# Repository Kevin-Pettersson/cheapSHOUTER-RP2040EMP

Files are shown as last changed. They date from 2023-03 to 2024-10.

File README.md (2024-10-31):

# cheapSHOUTER-RP2040EMP
Improved version of the great ChipSHOUTER-PicoEMP, this version has made cuts to the BOM and has added functionality inclduing: built in RP2040 instead of using a PICO, USB-C, LIPO charger + protection, USB isolation (not true isolation, allows to disconnect VBUS) + TVS diodes, buzzer, cleaner layout, and more.

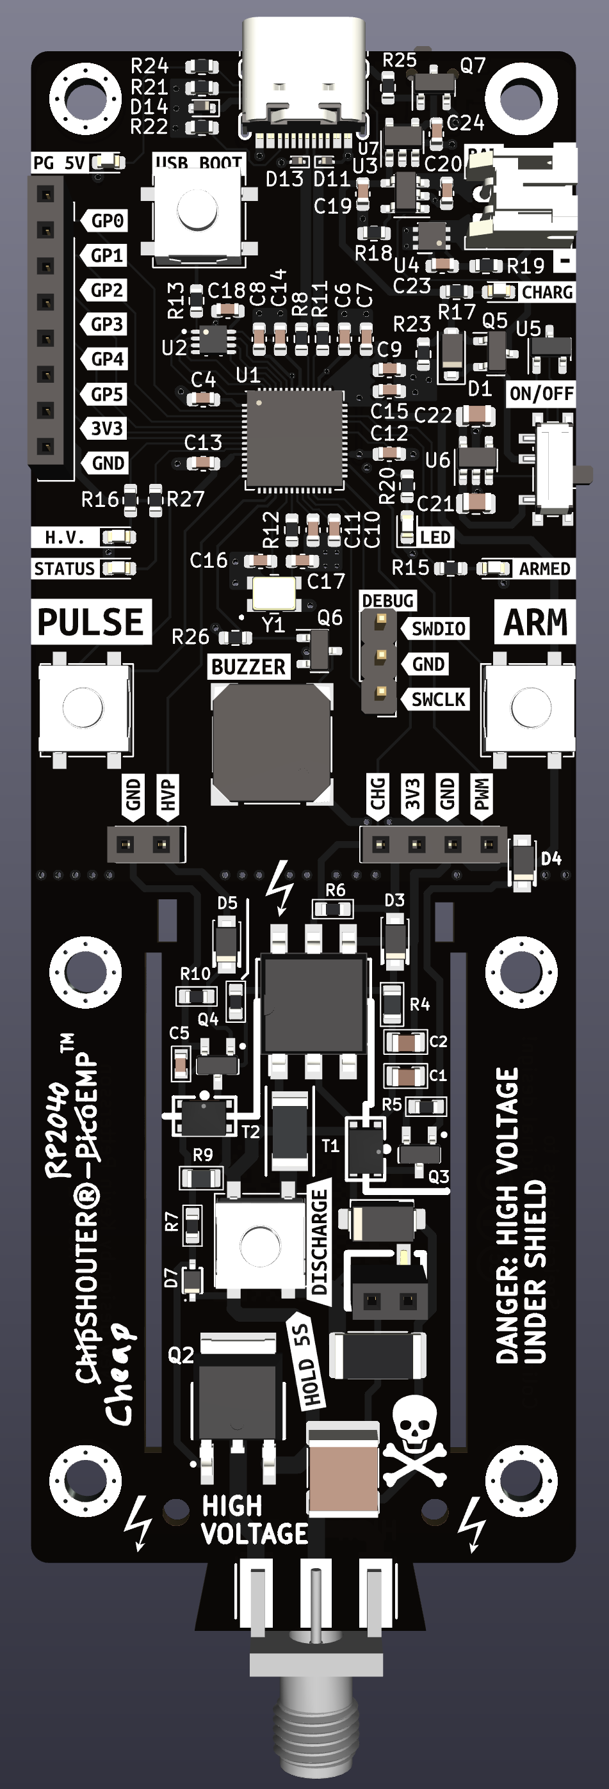
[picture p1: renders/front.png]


## Contributors
- Colin O'Flynn (original HW design)
- Nezza (original FW)
- Kevin Pettersson 
- Linus Backlund
- Wilhelm Westermark

## Firmware
The firmware is a slightly tweaked version of the c-firmware from the original repo. The changes adapts the button logic to the active-high board design and activates the buzzer for a short period upon manual pulses.

## License

This work is licensed under a [Creative Commons Attribution-ShareAlike 3.0 International License][cc-by-sa].

[cc-by-sa]: http://creativecommons.org/licenses/by-sa/3.0/
[cc-by-sa-image]: https://licensebuttons.net/l/by-sa/3.0/88x31.png
[cc-by-sa-shield]: https://img.shields.io/badge/License-CC%20BY--SA%203.0-lightgrey.svg

ChipSHOUTER is a trademark of NewAE Technology Inc., registered in the US, European Union, and other jurisdictions.
PicoEMP is a trademark of NewAE Technology Inc.

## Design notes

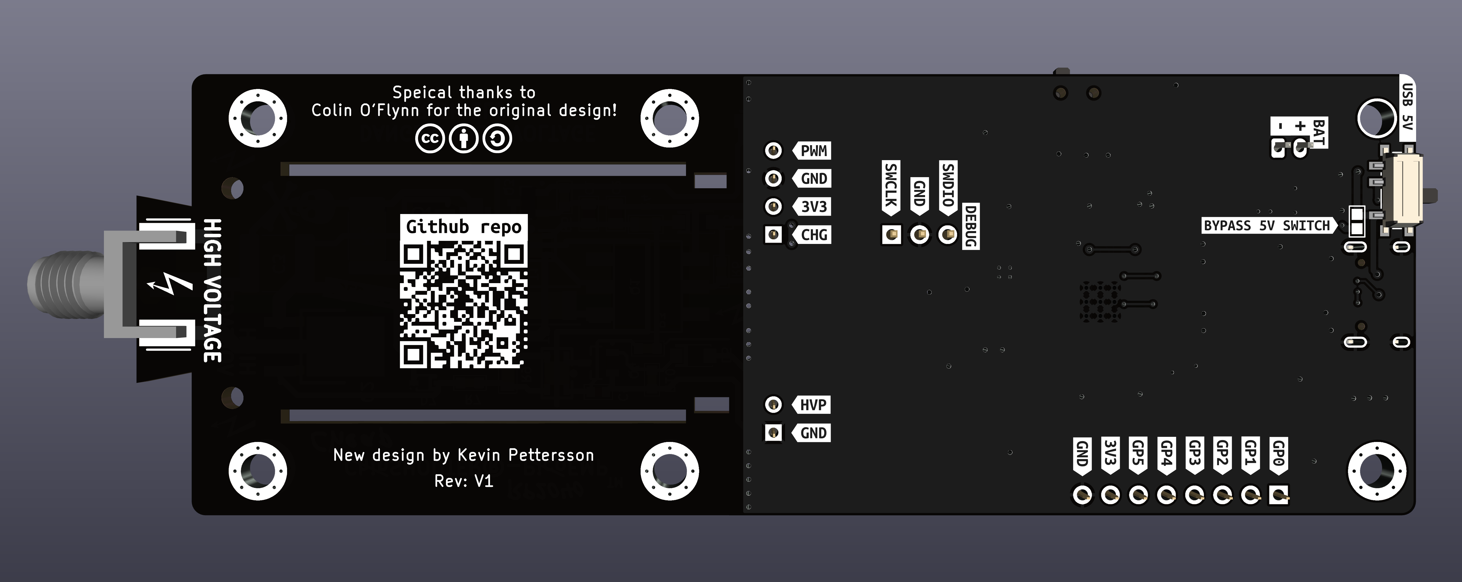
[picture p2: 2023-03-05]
renders/back_rotated.png

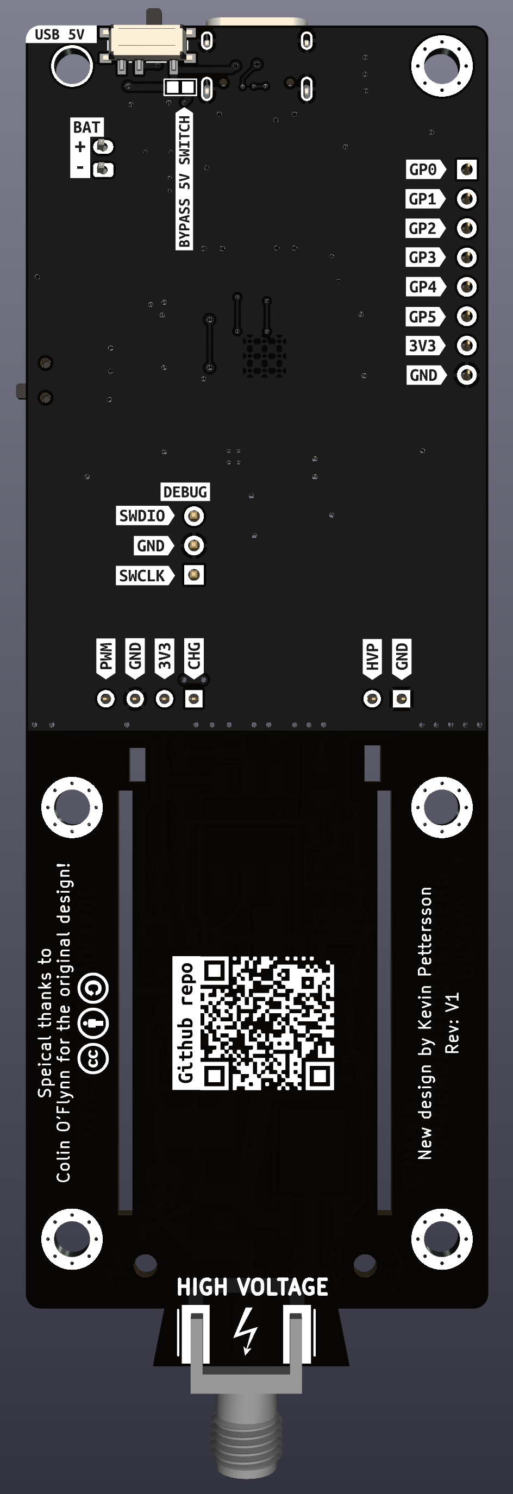
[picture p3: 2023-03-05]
renders/back.png

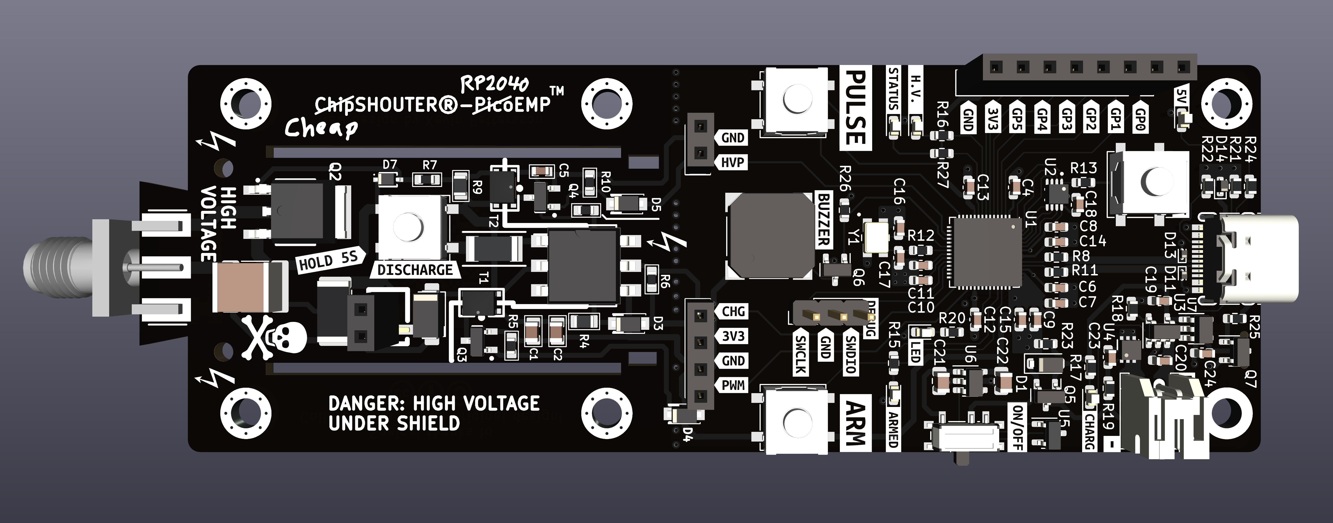
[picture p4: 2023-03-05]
renders/front_rotated.png

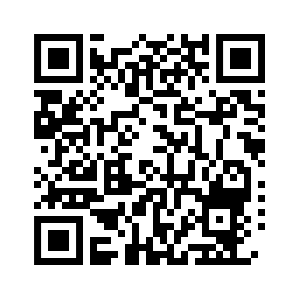
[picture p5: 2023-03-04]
qr_repo.png

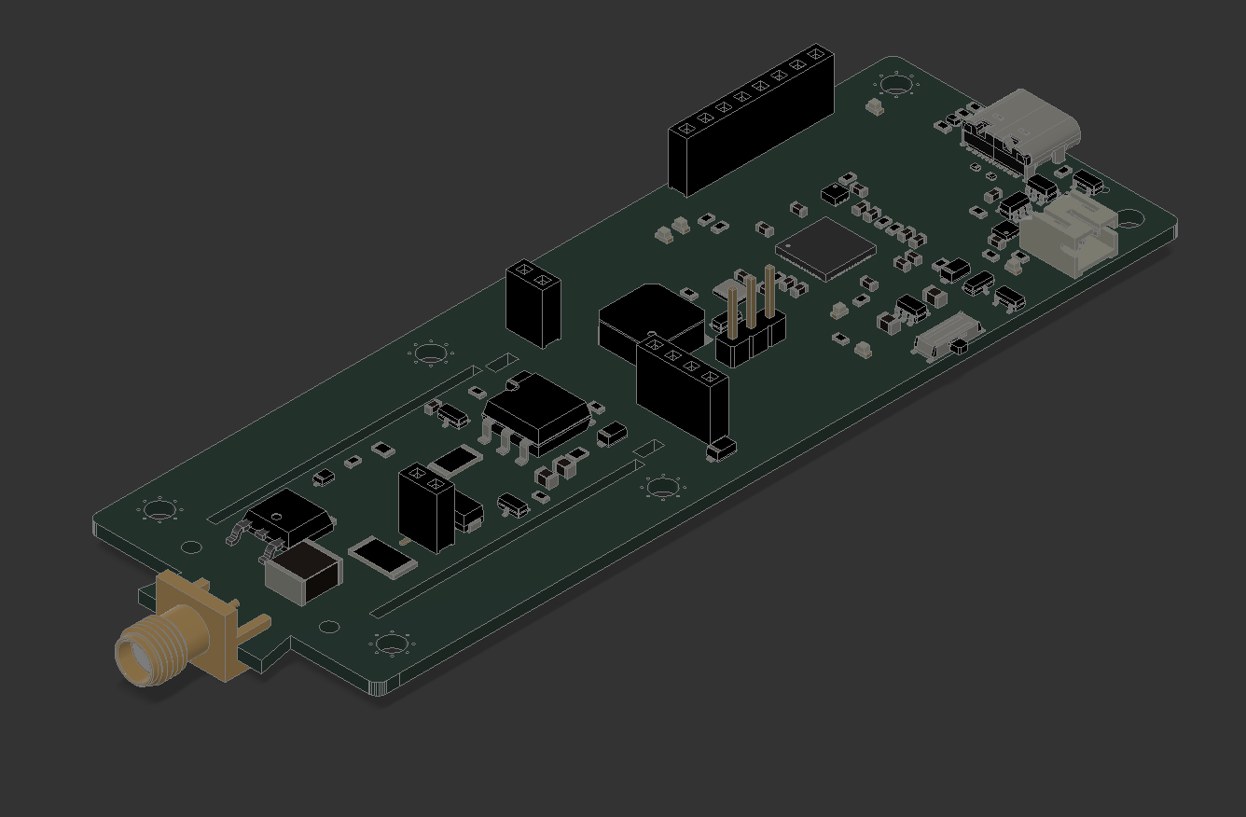
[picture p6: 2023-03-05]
renders/3d_model.png

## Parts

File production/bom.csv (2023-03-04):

Designator | Footprint | Quantity | Value | LCSC Part #
_2, |  | 2
BATTERY1 | JST_PH_S2B-PH-K_1x02_P2.00mm_Horizontal | 1 | Conn_01x02_Female
BZ1 | PUIAudio_SMT_0825_S_4_R | 1 | MLT-7525
C1, C2 | _Users_cofly_Dropbox (NewAE Technology Inc)_engineering_altium_Libraries_footprints_CAPC0805_M.PcbLib_CAPC0805_M | 2 | 4.7uF/50V
C10 | 0603 | 1 | 1u
C11 | 0603 | 1 | 100n
C12 | 0603 | 1 | 100n
C13 | 0603 | 1 | 100n
C14 | 0603 | 1 | 100n
C15 | 0603 | 1 | 1u
C16 | 0603 | 1 | 39p
C17 | 0603 | 1 | 39p
C18 | 0603 | 1 | 1u
C19 | 0603 | 1 | 10u
C20 | 0603 | 1 | 10u
C21 | 0805 | 1 | 47u
C22 | 0805 | 1 | 47u
C23 | 0603 | 1 | 100n
C24 | 0603 | 1 | 10u
C3 | 2220 | 1 | 0.47uF,630V,X7T
C4 | 0603 | 1 | 100n
C5 | _Users_cofly_Dropbox (NewAE Technology Inc)_engineering_altium_Libraries_footprints_CAPC0603_M.PcbLib_CAPC0603_M | 1 | 100n
C6 | 0603 | 1 | 100n
C7 | 0603 | 1 | 100n
C8 | 0603 | 1 | 100n
C9 | 0603 | 1 | 100n
D1 | D_SOD-123F | 1 | DS14W
D10 | 0603 | 1 | PICO_LED1
D11, D13 | D_SOD-923 | 2 | LESD9L5.0T5G
D12 | 0603 | 1 | STATUS1
D14 | D_SOD-523 | 1 | PESDNC5D7VU
D15 | 0603 | 1 | 5V_PWR
D2 | _Users_cofly_Dropbox (NewAE Technology Inc)_engineering_altium_Libraries_footprints_DO-214AC.PcbLib_DO-214AC | 1 | MURA160T3G
D3, D4, D5 | _Users_cofly_Dropbox (NewAE Technology Inc)_engineering_altium_NewAE_AltiumLib.DBLib/main_DSS13UTR | 3 | GOODWORK A7
D6 | 0603 | 1 | CHARGING
D7 | _Users_colin_Dropbox (NewAE Technology Inc)_engineering_altium_Libraries_footprints_SOD323.PcbLib_SOD323 | 1 | MM3Z18VB
D8 | 0603 | 1 | CHARGE_ON1
D9 | 0603 | 1 | H.V_DETECTED1
J1 | _Users_cofly_Dropbox (NewAE Technology Inc)_engineering_altium_Libraries_footprints_CON-SMA-MALE-PCB-EDGE062.PcbLib_CON-SMA-MALE-PCB-EDGE062 | 1 | EDGE-SMA
J2 | USB_C_Receptacle_HRO_TYPE-C-31-M-12 | 1 | USB_C_Receptacle_USB2.0 | C709357
J3 | _Users_cofly_Dropbox (NewAE Technology Inc)_engineering_altium_Libraries_footprints_GCT_BG306.PcbLib_BG306-R2-2PIN | 1 | BG306-02-A-2-0400-L-G
J5 | PinHeader_1x03_P2.54mm_Vertical | 1 | Conn_01x03_Socket
J6 | PinSocket_1x08_P2.54mm_Vertical | 1 | Conn_01x08_Socket
JP1 | SolderJumper-2_P1.3mm_Open_Pad1.0x1.5mm | 1 | ~
MH1_5, MH1_4, MH1_3, MH1_2, MH1 | _Users_colin_Dropbox (NewAE Technology Inc)_engineering_altium_Libraries_footprints_MOUNT_M3_TIGHT.PcbLib_MOUNT_M3_TIGHT | 5 | M3, Tight Fit
P2 | HDR1X2 | 1 | Header 2
P3 | HDR1X4 | 1 | Header 4
Q1 | SOP254P952X470-6N | 1 | LDA111STR
Q2 | _Users_cofly_Dropbox (NewAE Technology Inc)_engineering_altium_Libraries_footprints_DPAK_TO-252AA_M.PcbLib_DPAK_TO-252AA_M | 1 | RGT16BM65DTL
Q3, Q4 | _Users_cofly_Dropbox (NewAE Technology Inc)_engineering_altium_Libraries_footprints_SOT95P245X110-3M.PcbLib_SOT95P245X110-3M | 2 | AO3422
Q5 | SOT-23 | 1 | FSS2301S
Q6 | SOT-23 | 1 | FSS2302S
Q7 | SOT-23 | 1 | FSS2302S
R1 | _Users_cofly_Dropbox (NewAE Technology Inc)_engineering_altium_NewAE_AltiumLib.DBLib/main_RESC5025X06N | 1 | 20M
R10, R5 | _Users_cofly_Dropbox (NewAE Technology Inc)_engineering_altium_Libraries_footprints_RESC1608X55N.PcbLib_RESC1608X55N | 2 | 1k
R11 | 0603 | 1 | 27
R12 | 0603 | 1 | 200
R13 | 0603 | 1 | 1K
R15 | 0603 | 1 | 1k
R16 | 0603 | 1 | 1k
R17 | 0603 | 1 | 2k
R18 | 0603 | 1 | 2k
R19 | 0603 | 1 | 100
R2 | 2512 | 1 | 360k
R20 | 0603 | 1 | 1k
R21 | 0603 | 1 | 5.1K | C23186
R22 | 0603 | 1 | 5.1K
R23 | 0603 | 1 | 10k
R24 | 0603 | 1 | 1k
R25 | 0603 | 1 | 100k
R26 | 0603 | 1 | 100k
R27 | 0603 | 1 | 1k
R3 | _Users_cofly_Dropbox (NewAE Technology Inc)_engineering_altium_NewAE_AltiumLib.DBLib/main_RESC1608X55N | 1 | 10R
R4 | _Users_cofly_Dropbox (NewAE Technology Inc)_engineering_altium_Libraries_footprints_RESC2012X70N.PcbLib_RESC2012X70N | 1 | 75R
R6 | _Users_colin_Dropbox (NewAE Technology Inc)_engineering_altium_Libraries_footprints_RESC1608X55N.PcbLib_RESC1608X55N | 1 | 22k
R7 | _Users_cofly_Dropbox (NewAE Technology Inc)_engineering_altium_Libraries_footprints_RESC1608X55N.PcbLib_RESC1608X55N | 1 | 10R
R8 | 0603 | 1 | 27
R9 | _Users_cofly_Dropbox (NewAE Technology Inc)_engineering_altium_Libraries_footprints_RESC2012X70N.PcbLib_RESC2012X70N | 1 | 2k
SW1 | _Users_cofly_Dropbox (NewAE Technology Inc)_engineering_altium_Libraries_footprints_CK_KSC7J.PcbLib_CK_KSC7J | 1 | ARM
SW2 | _Users_cofly_Dropbox (NewAE Technology Inc)_engineering_altium_Libraries_footprints_CK_KSC7J.PcbLib_CK_KSC7J | 1 | PULSE
SW3 | _Users_colin_Dropbox (NewAE Technology Inc)_engineering_altium_Libraries_footprints_CK_KSC7J.PcbLib_CK_KSC7J | 1 | TL3301AF160QJ
SW4 | _Users_cofly_Dropbox (NewAE Technology Inc)_engineering_altium_Libraries_footprints_CK_KSC7J.PcbLib_CK_KSC7J | 1 | SW_SPST
SW5, SW6 | SW_SPDT_PCM12 | 2 | SSSS811101
T1, T2 | _Users_cofly_Dropbox (NewAE Technology Inc)_engineering_altium_Libraries_footprints_ATB322524.PcbLib_ATB322524 | 2 | ATB322524
U1 | QFN-56-1EP_7x7mm_P0.4mm_EP3.2x3.2mm | 1 | RP2040 | C2040
U2 | IC_W25Q16JVUXIQ_TR | 1 | W25Q128JVSIQ
U3 | SOT-23-5 | 1 | LP4054H
U4 | DFN-6-1EP_2x2mm_P0.65mm_EP1x1.6mm | 1 | XB6536A
U5 | SOT-23-3 | 1 | ME2807
U6 | SOT-23-5 | 1 | LP3992-3.3
U7 | SOT-23-5 | 1 | LPW5206
Y1 | X322512MSB4SI | 1 | X322512MSB4SI

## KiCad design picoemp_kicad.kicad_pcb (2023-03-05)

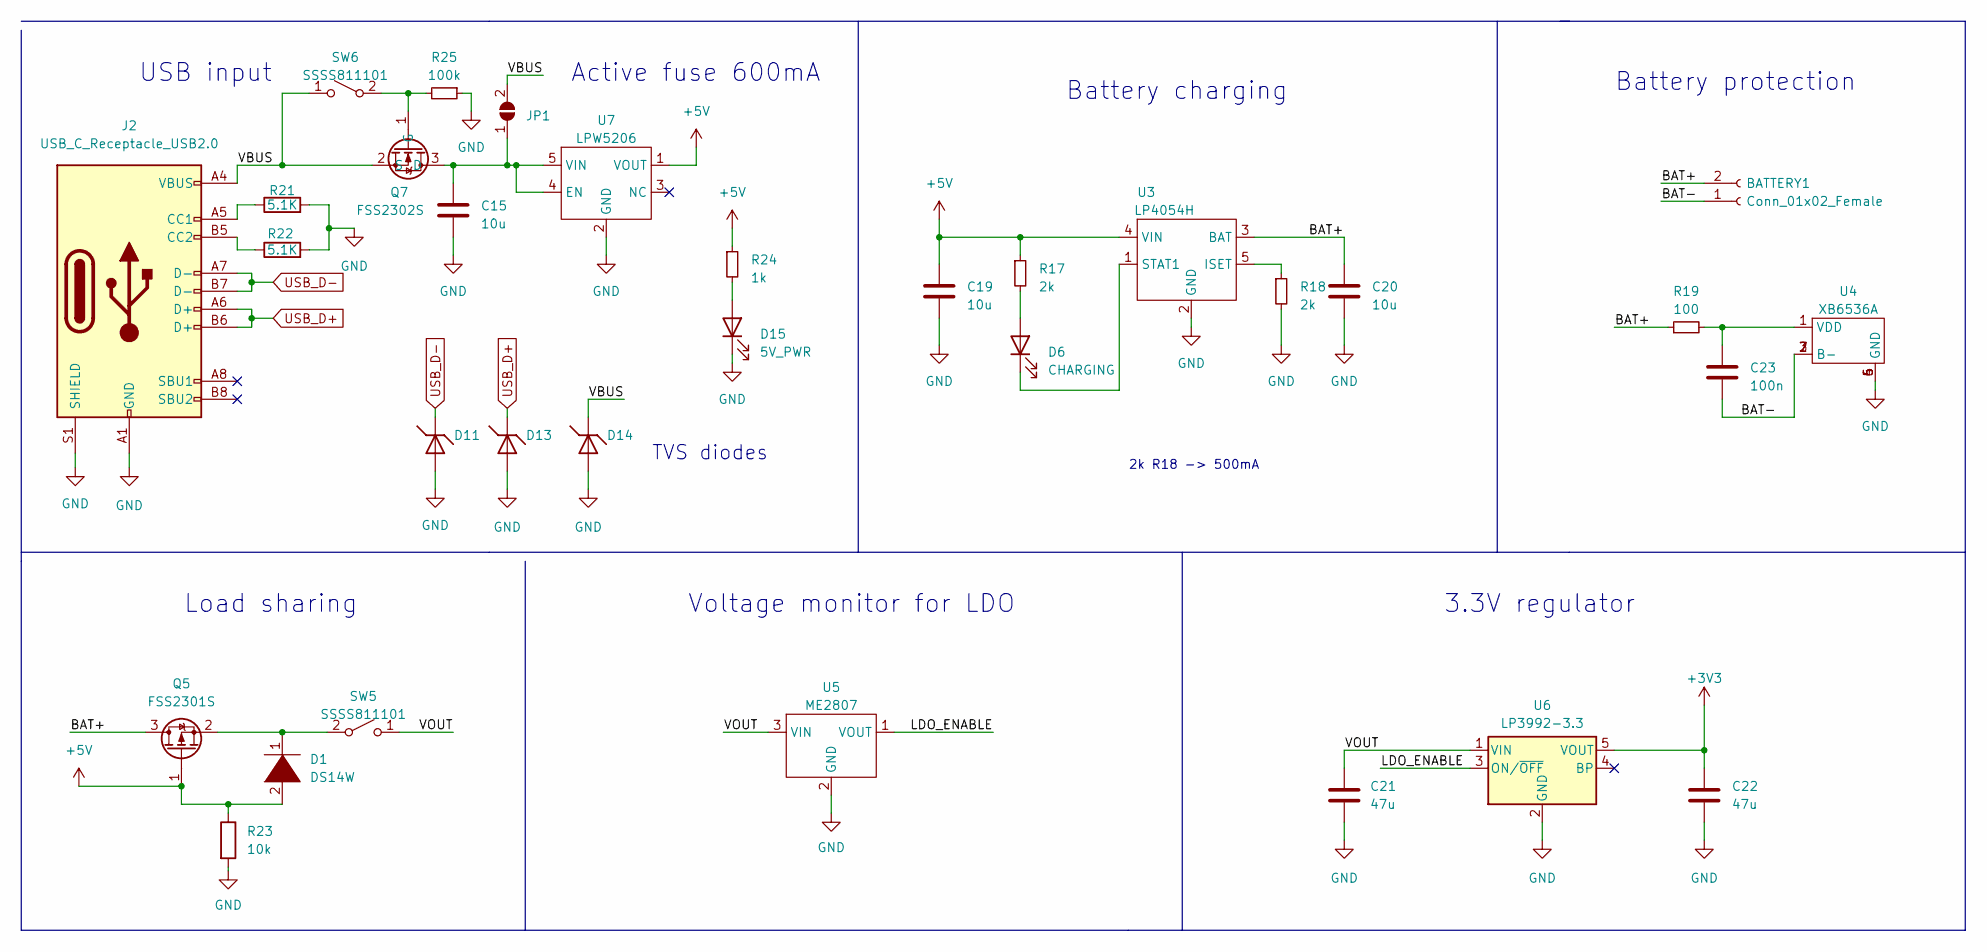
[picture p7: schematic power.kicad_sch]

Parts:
BATTERY1: Conn_01x02_Female; JST_PH_S2B-PH-K_1x02_P2.00mm_Horizontal
C15, C19, C20: 10u; C_0603_1608Metric
C21, C22: 47u; C_0805_2012Metric
C23: 100n; C_0603_1608Metric
D1: DS14W; D_SOD-123F
D6: CHARGING; LED_0603_1608Metric
D11, D13: LESD9L5.0T5G; D_SOD-923
D14: PESDNC5D7VU; D_SOD-523
D15: 5V_PWR; LED_0603_1608Metric
J2: USB_C_Receptacle_USB2.0; USB_C_Receptacle_HRO_TYPE-C-31-M-12; JLCPCB Part # C709357
JP1: SolderJumper-2_P1.3mm_Open_Pad1.0x1.5mm
Q5: FSS2301S; SOT-23
Q7: FSS2302S; SOT-23
R17, R18: 2k; R_0603_1608Metric
R19: 100; R_0603_1608Metric
R21: 5.1K; R_0603_1608Metric; JLCPCB Part # C23186
R22: 5.1K; R_0603_1608Metric
R23: 10k; R_0603_1608Metric
R24: 1k; R_0603_1608Metric
R25: 100k; R_0603_1608Metric
SW5, SW6: SSSS811101; SW_SPDT_PCM12
U3: LP4054H; SOT-23-5
U4: XB6536A; DFN-6-1EP_2x2mm_P0.65mm_EP1x1.6mm
U5: ME2807; SOT-23-3
U6: LP3992-3.3; SOT-23-5
U7: LPW5206; SOT-23-5

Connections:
+5V: C19.1, D1.2 (K), Q5.1 (G), R17.1, R23.1, R24.1, U3.4 (VIN), U7.1 (VOUT)
/Power/BAT+: BATTERY1.2 (Pin_1), C20.1, Q5.3 (D), R19.1, U3.3 (BAT)
/Power/BAT-: BATTERY1.1 (Pin_2), C23.2, U4.2 (B-), U4.3 (B-), U4.7 (B-)
/Power/LDO_ENABLE: U5.1 (VOUT), U6.3 (ON/~OFF)
/Power/VBUS: D14.1 (K), J2.A4 (VBUS), J2.A9 (VBUS), J2.B4 (VBUS), J2.B9 (VBUS), JP1.2 (B), Q7.2 (S), SW6.1 (B)
/Power/VOUT: C21.1, SW5.1 (B), U5.3 (VIN), U6.1 (VIN)
GND: C15.2, C19.2, C20.2, C21.2, C22.2, D11.2 (A), D13.2 (A), D14.2 (A), D15.1 (K), J2.A1 (GND), J2.A12 (GND), J2.B1 (GND), J2.B12 (GND), J2.S1 (SHIELD), R18.2, R21.2, R22.2, R23.2, R25.1, U3.2 (GND), U4.4 (GND), U4.5 (GND), U4.6 (GND), U5.2 (GND), U6.2 (GND), U7.2 (GND); also elsewhere on the board
unnamed: D1.1 (A), Q5.2 (S), SW5.2 (A)
unnamed: D6.2 (A), R17.2
unnamed: D6.1 (K), U3.1 (STAT1)
unnamed: D15.2 (A), R24.2
unnamed: J2.A5 (CC1), R21.1
unnamed: J2.B5 (CC2), R22.1
unnamed: Q7.1 (G), R25.2, SW6.2 (A)
unnamed: R18.1, U3.5 (ISET)
unnamed: C23.1, R19.2, U4.1 (VDD)
USB_D+: D13.1 (K), J2.A6 (D+), J2.B6 (D+); also elsewhere on the board
USB_D-: D11.1 (K), J2.A7 (D-), J2.B7 (D-); also elsewhere on the board

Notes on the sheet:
2k R18 -> 500mA
Battery protection
USB input
Battery charging
Voltage monitor for LDO
Active fuse 600mA
TVS diodes
3.3V regulator
Load sharing

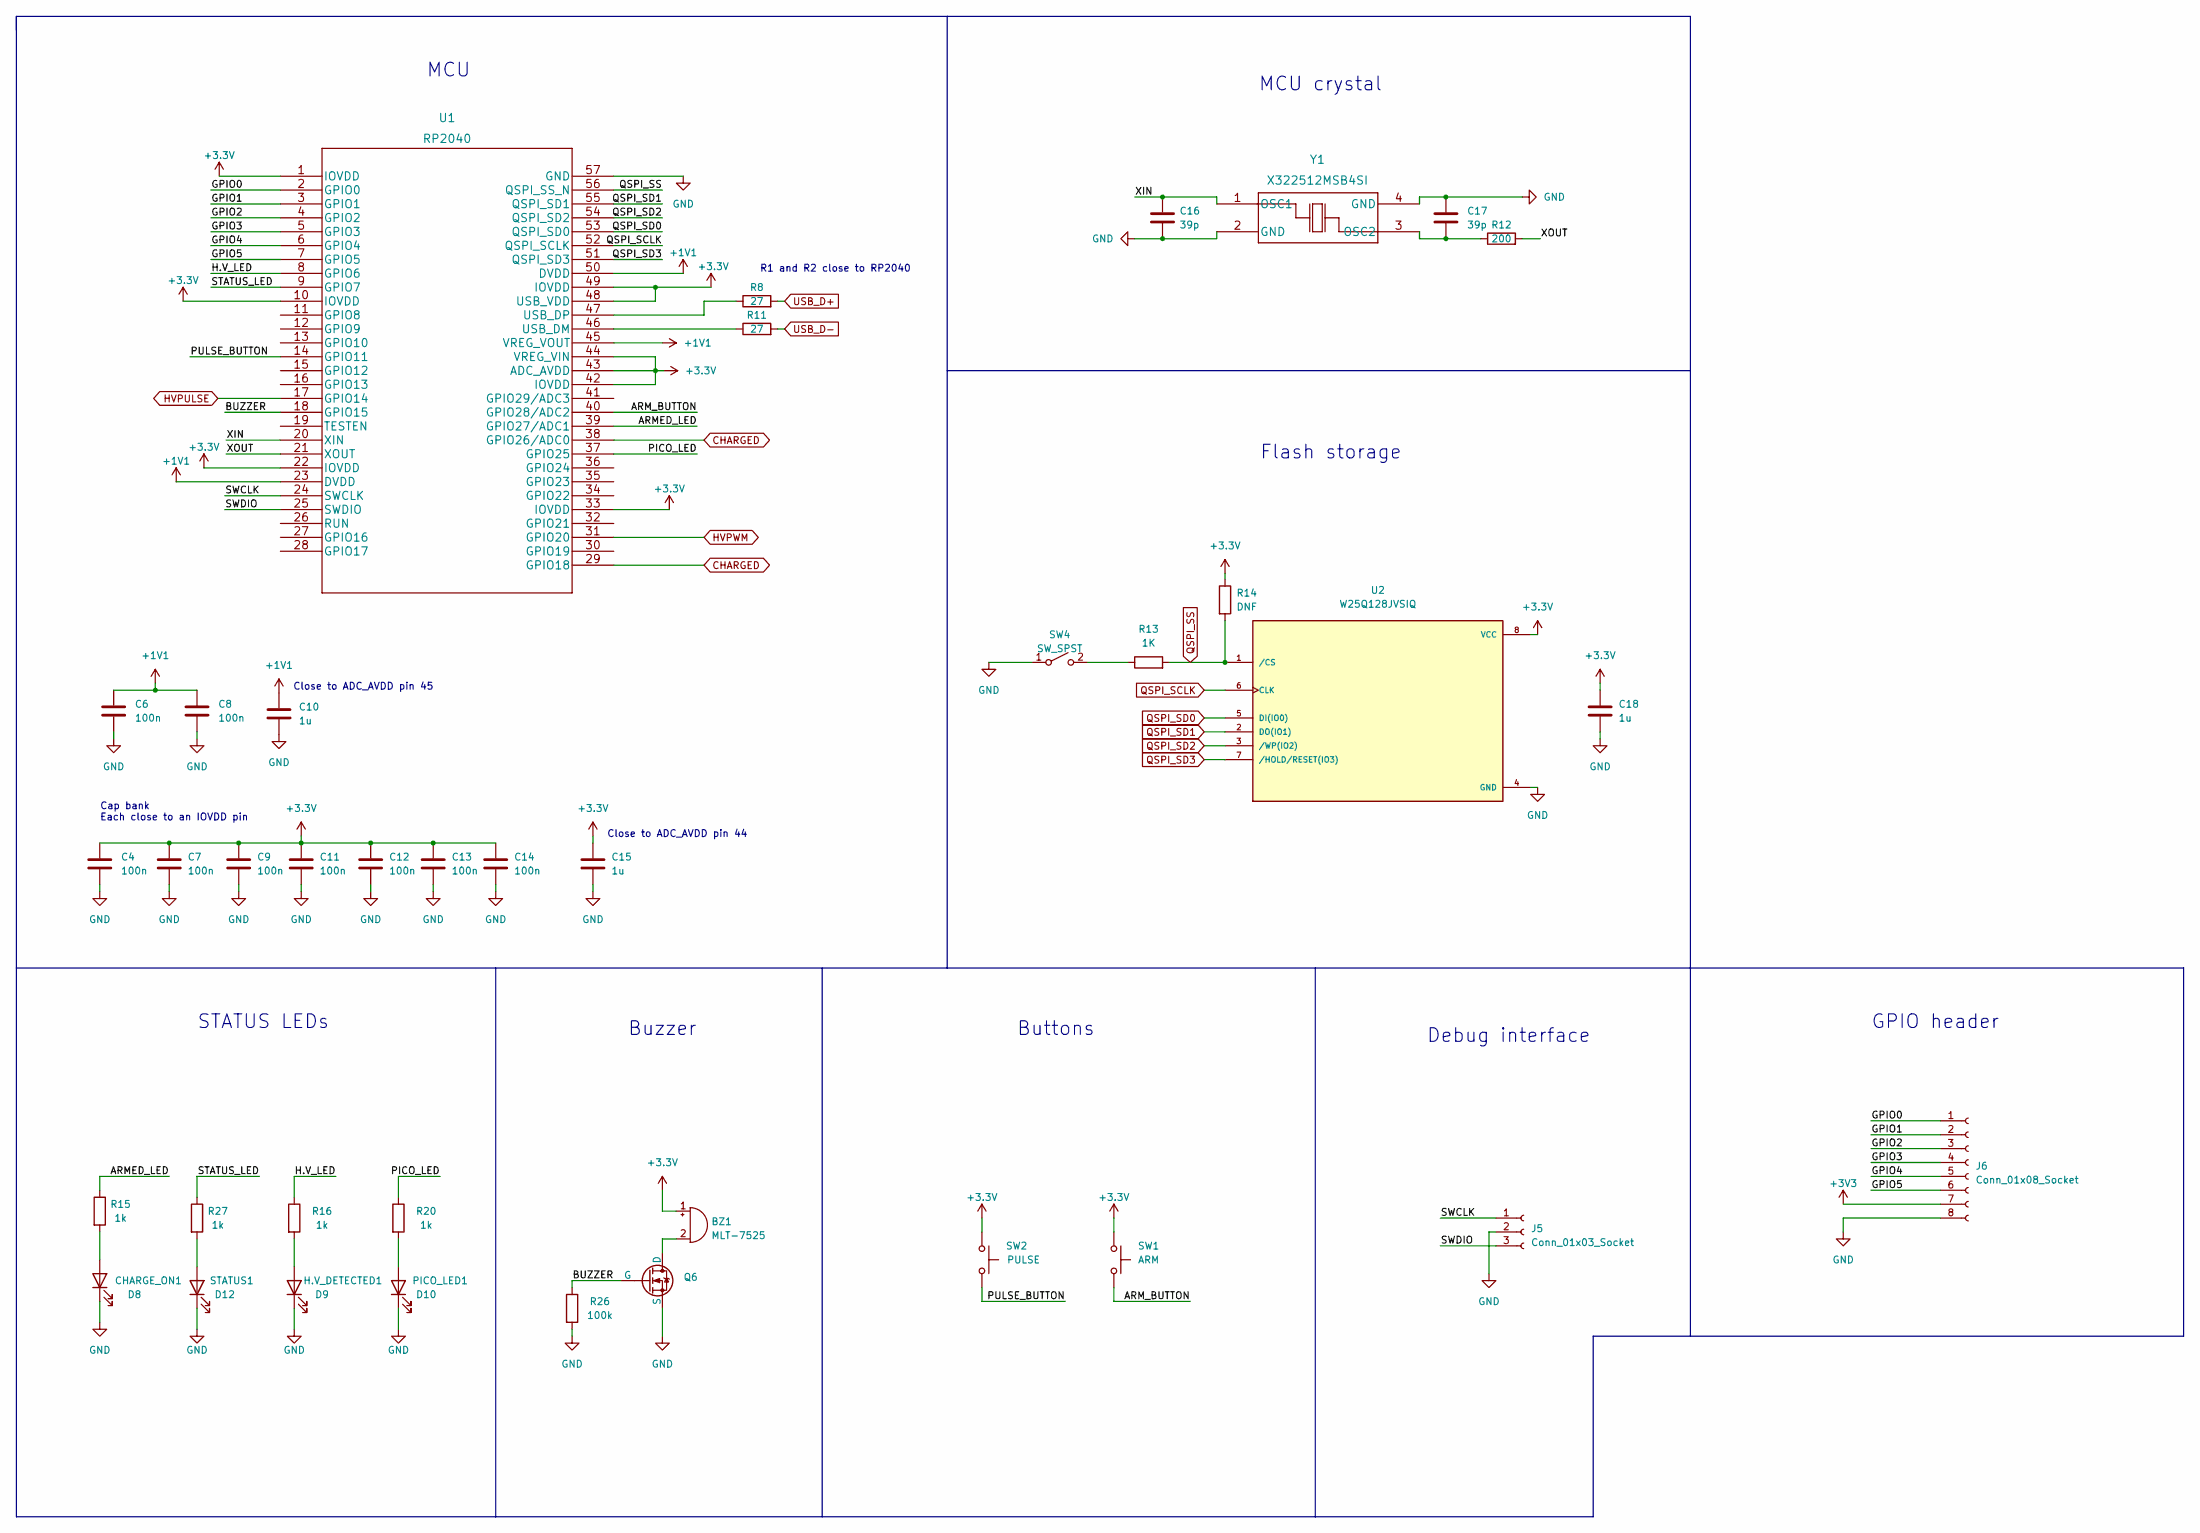
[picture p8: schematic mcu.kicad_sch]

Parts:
BZ1: MLT-7525; PUIAudio_SMT_0825_S_4_R
C4, C6, C7, C8, C9, C11, C12, C13, C14: 100n; C_0603_1608Metric
C10, C15, C18: 1u; C_0603_1608Metric
C16, C17: 39p; C_0603_1608Metric
D8: CHARGE_ON1; LED_0603_1608Metric
D9: H.V_DETECTED1; LED_0603_1608Metric
D10: PICO_LED1; LED_0603_1608Metric
D12: STATUS1; LED_0603_1608Metric
J5: Conn_01x03_Socket; PinHeader_1x03_P2.54mm_Vertical
J6: Conn_01x08_Socket; PinSocket_1x08_P2.54mm_Vertical
Q6: FSS2302S; SOT-23
R8, R11: 27; R_0603_1608Metric
R12: 200; R_0603_1608Metric
R13: 1K; R_0603_1608Metric
R14: DNF
R15, R16, R20, R27: 1k; R_0603_1608Metric
R26: 100k; R_0603_1608Metric
SW1: ARM
SW2: PULSE
SW4: SW_SPST; SW_SPST_CK_RS282G05A3
U1: RP2040; QFN-56-1EP_7x7mm_P0.4mm_EP3.2x3.2mm; JLCPCB Part # C2040
U2: W25Q128JVSIQ; IC_W25Q16JVUXIQ_TR; PARTREV I
Y1: X322512MSB4SI

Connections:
+1V1: C6.1, C8.1, C10.1, U1.23 (DVDD), U1.45 (VREG_VOUT), U1.50 (DVDD)
/RP2040/ARMED_LED: R15.1, U1.39 (GPIO27/ADC1)
/RP2040/ARM_BUTTON: SW1.1, U1.40 (GPIO28/ADC2)
/RP2040/BUZZER: Q6.1 (G), R26.1, U1.18 (GPIO15)
/RP2040/GPIO0: J6.1, U1.2 (GPIO0)
/RP2040/GPIO1: J6.2, U1.3 (GPIO1)
/RP2040/GPIO2: J6.3, U1.4 (GPIO2)
/RP2040/GPIO3: J6.4, U1.5 (GPIO3)
/RP2040/GPIO4: J6.5, U1.6 (GPIO4)
/RP2040/GPIO5: J6.6, U1.7 (GPIO5)
/RP2040/H.V_LED: R16.1, U1.8 (GPIO6)
/RP2040/PICO_LED: R20.1, U1.37 (GPIO25)
/RP2040/PULSE_BUTTON: SW2.2, U1.14 (GPIO11)
/RP2040/STATUS_LED: R27.1, U1.9 (GPIO7)
/RP2040/SWCLK: J5.1, U1.24 (SWCLK)
/RP2040/SWDIO: J5.3, U1.25 (SWDIO)
/RP2040/XIN: C16.1, U1.20 (XIN), Y1.1 (OSC1)
CHARGED: U1.29 (GPIO18), U1.38 (GPIO26/ADC0); also elsewhere on the board
GND: C4.2, C6.2, C7.2, C8.2, C9.2, C10.2, C11.2, C12.2, C13.2, C14.2, C15.2, C16.2, C17.1, C18.2, D8.1 (K), D9.1 (K), D10.1 (K), D12.1 (K), J5.2, J6.8, Q6.2 (S), R26.2, SW4.1 (A), U1.57 (GND), U2.4 (GND), Y1.2 (GND), Y1.4 (GND); also elsewhere on the board
HVPULSE: U1.17 (GPIO14); also elsewhere on the board
HVPWM: U1.31 (GPIO20); also elsewhere on the board
unnamed: BZ1.2 (-), Q6.3 (D)
unnamed: D8.2 (A), R15.2
unnamed: D9.2 (A), R16.2
unnamed: D10.2 (A), R20.2
unnamed: D12.2 (A), R27.2
unnamed: R13.1, SW4.2 (B)
unnamed: R11.1, U1.46 (USB_DM)
unnamed: R8.1, U1.47 (USB_DP)
QSPI_SCLK: U1.52 (QSPI_SCLK), U2.6 (CLK)
QSPI_SD0: U1.53 (QSPI_SD0), U2.5 (DI(IO0))
QSPI_SD1: U1.55 (QSPI_SD1), U2.2 (DO(IO1))
QSPI_SD2: U1.54 (QSPI_SD2), U2.3 (/WP(IO2))
QSPI_SD3: U1.51 (QSPI_SD3), U2.7 (/HOLD/RESET(IO3))
USB_D+: R8.2; also elsewhere on the board
USB_D-: R11.2; also elsewhere on the board

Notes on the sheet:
Cap bank Each close to an IOVDD pin
R1 and R2 close to RP2040
Buttons
MCU crystal
MCU
STATUS LEDs
Close to ADC_AVDD pin 45
Debug interface
Buzzer
Flash storage
Close to ADC_AVDD pin 44
GPIO header

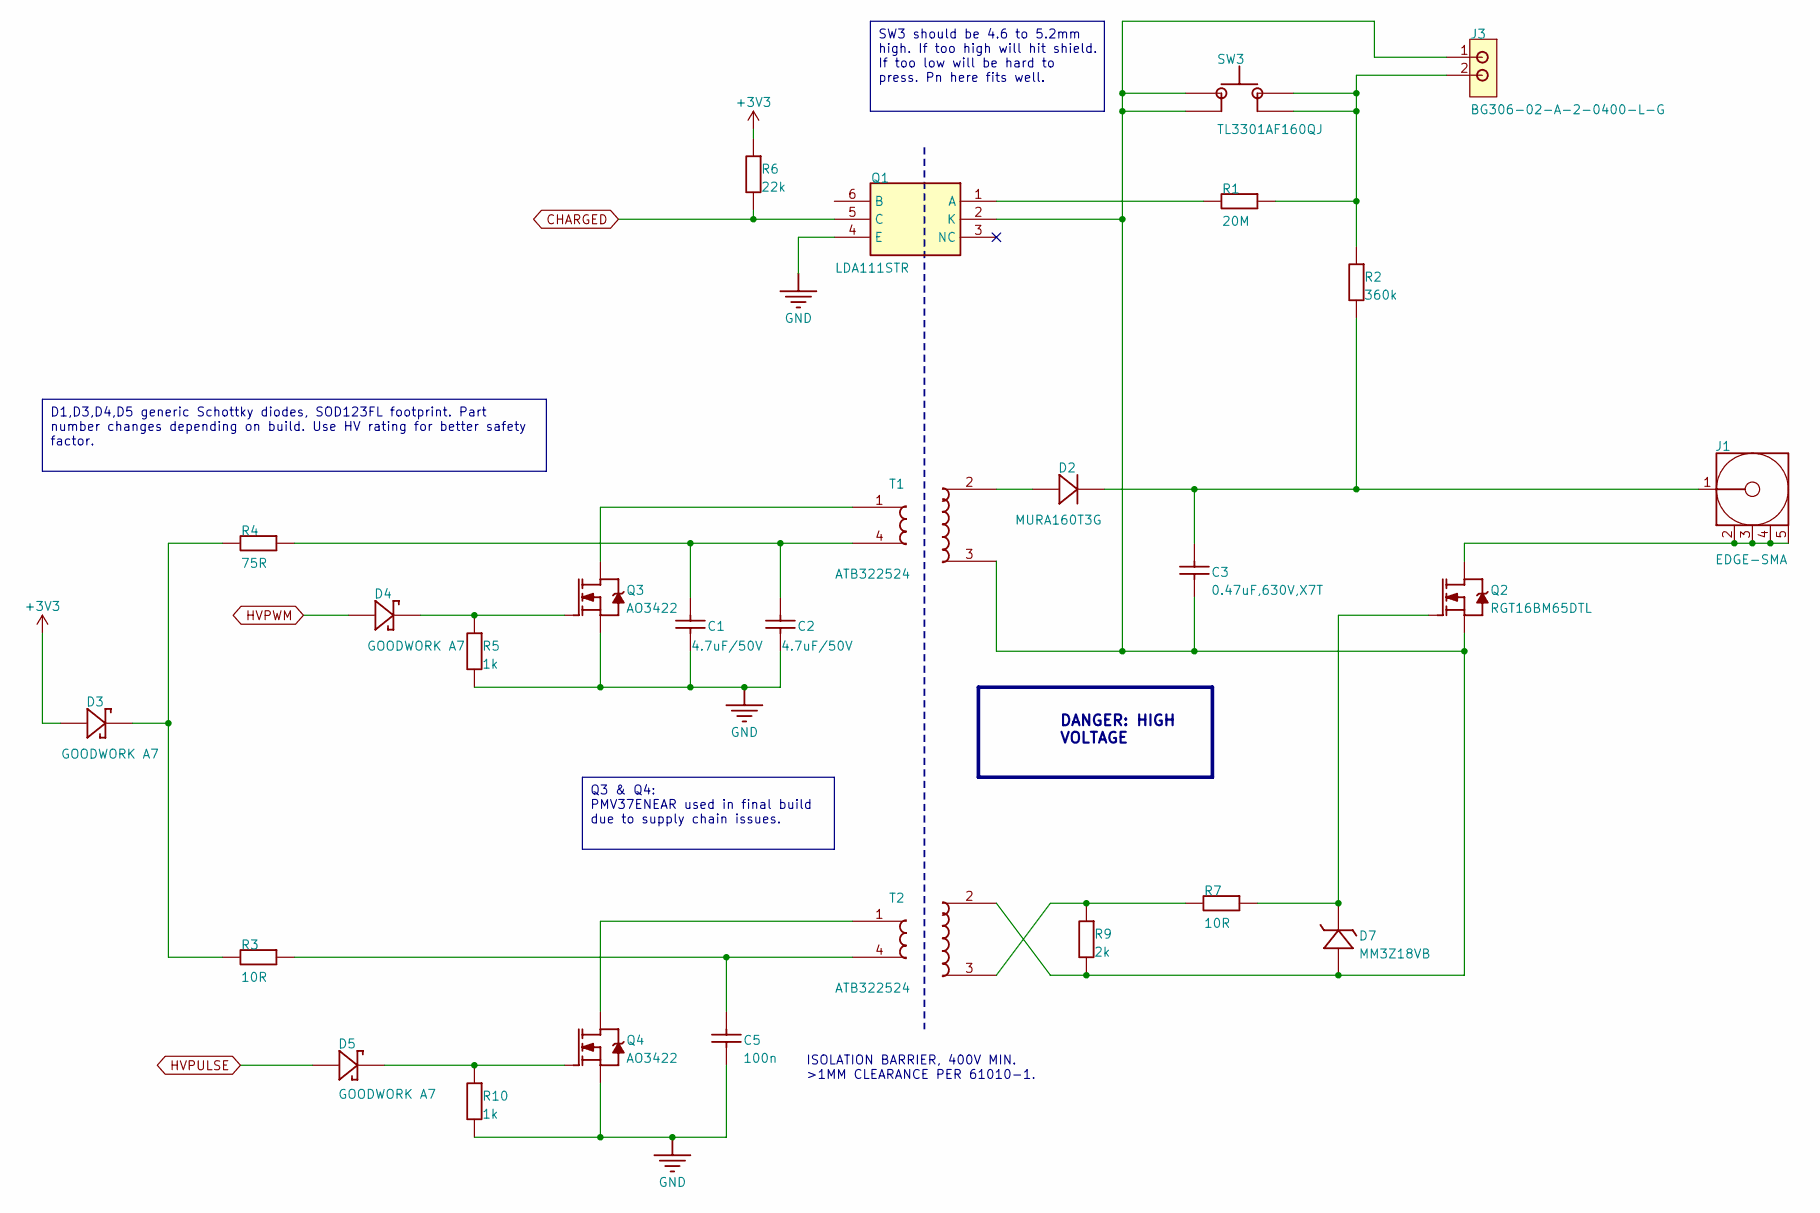
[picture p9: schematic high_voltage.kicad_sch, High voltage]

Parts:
C1, C2: 4.7uF/50V; CAPC0805_M; RATED VOLTAGE 50VDC; TOLERANCE 10%; PART NUMBER CCHIP-4u7-0805-50V
C3: 0.47uF,630V,X7T; C_2220_5650Metric; RATED VOLTAGE 630V; TOLERANCE +22/-30; PART NUMBER KRM55TR72J474MH01K
C5: 100n; CAPC0603_M; RATED VOLTAGE 50VDC; PART NUMBER CCHIP-100n-0603
D2: MURA160T3G; DO-214AC; RATED VOLTAGE 600V; PART NUMBER MURA160T3G
D3, D4, D5: GOODWORK A7; DSS13UTR; PART NUMBER DSS13UTR
D7: MM3Z18VB; SOD323; RATED VOLTAGE 10V; TOLERANCE 2%; PART NUMBER MM3Z18VB
J1: EDGE-SMA; CON-SMA-MALE-PCB-EDGE062; PART NUMBER CON-F-SMA-PCBEDGE-003.062
J3: BG306-02-A-2-0400-L-G; BG306-R2-2PIN; PART NUMBER BG306-02-A-2-0400-L-G
Q1: LDA111STR; _Users_colin_Documents_AltiumLL_SamacSys.PcbLib_SOP254P952X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; MANUFACTURER_PART_NUMBER LDA111STR; MOUSER PART NUMBER 849-LDA111STR
Q2: RGT16BM65DTL; DPAK_TO-252AA_M; RATED VOLTAGE 100V; PART NUMBER IRLR120TRPBF
Q3, Q4: AO3422; SOT95P245X110-3M; RATED VOLTAGE 30V; PART NUMBER DMN3200U-7
R1: 20M; RESC5025X06N; RATED VOLTAGE 400VDC; TOLERANCE 1%; PART NUMBER RCHIP-20M-2010
R2: 360k; RESC6432X06N; RATED VOLTAGE 250V; TOLERANCE 1%; PART NUMBER RCHIP-300K-2510
R3, R7: 10R; RESC1608X55N; RATED VOLTAGE 75VDC; TOLERANCE 1%; PART NUMBER RCHIP-10R-0603
R4: 75R; RESC2012X70N; RATED VOLTAGE 75VDC; TOLERANCE 1%; PART NUMBER RCHIP-75R-0805
R5, R10: 1k; RESC1608X55N; RATED VOLTAGE 75VDC; TOLERANCE 1%; PART NUMBER RCHIP-1K-0603
R6: 22k; RESC1608X55N; RATED VOLTAGE 75VDC; TOLERANCE 1%; PART NUMBER RCHIP-22K-0603
R9: 2k; RESC2012X70N; RATED VOLTAGE 75VDC; TOLERANCE 1%; PART NUMBER RCHIP-75R-0805
SW3: TL3301AF160QJ; CK_KSC7J; PART NUMBER TACTSW-KSC741J
T1, T2: ATB322524; ATB322524_CHUNKY; PART NUMBER ATB322524_PROTO

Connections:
CHARGED: Q1.5 (C), R6.2; also elsewhere on the board
GND: C1.2, C2.2, C5.2, Q1.4 (E), Q3.2 (S), Q4.2 (S), R5.2, R10.2; also elsewhere on the board
HVPULSE: D5.A; also elsewhere on the board
HVPWM: D4.A; also elsewhere on the board
unnamed: C1.1, C2.1, R4.2, T1.4
unnamed: C5.1, R3.2, T2.4
unnamed: D2.A, T1.2
unnamed: D3.K, R3.1, R4.1
unnamed: C3.1, D2.K, J1.1 (Signal), R2.2
unnamed: J3.2, R1.2, R2.1, SW3.2 (IN), SW3.3 (IN)
unnamed: Q1.1 (A), R1.1
unnamed: C3.2, D7.A, J3.1, Q1.2 (K), Q2.2 (S), R9.2, SW3.1 (IN), SW3.4 (IN), T1.3, T2.2
unnamed: J1.2 (GND), J1.3 (GND), J1.4 (GND), J1.5 (GND), Q2.3 (D)
unnamed: D7.K, Q2.1 (G), R7.2
unnamed: Q3.3 (D), T1.1
unnamed: D4.K, Q3.1 (G), R5.1
unnamed: Q4.3 (D), T2.1
unnamed: D5.K, Q4.1 (G), R10.1
unnamed: R7.1, R9.1, T2.3

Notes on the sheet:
Q3 & Q4: PMV37ENEAR used in final build due to supply chain issues.
D1,D3,D4,D5 generic Schottky diodes, SOD123FL footprint. Part number changes depending on build. Use HV rating for better safety factor.
SW3 should be 4.6 to 5.2mm high. If too high will hit shield. If too low will be hard to press. Pn here fits well.
ISOLATION BARRIER, 400V MIN. >1MM CLEARANCE PER 61010-1.
DANGER: HIGH VOLTAGE

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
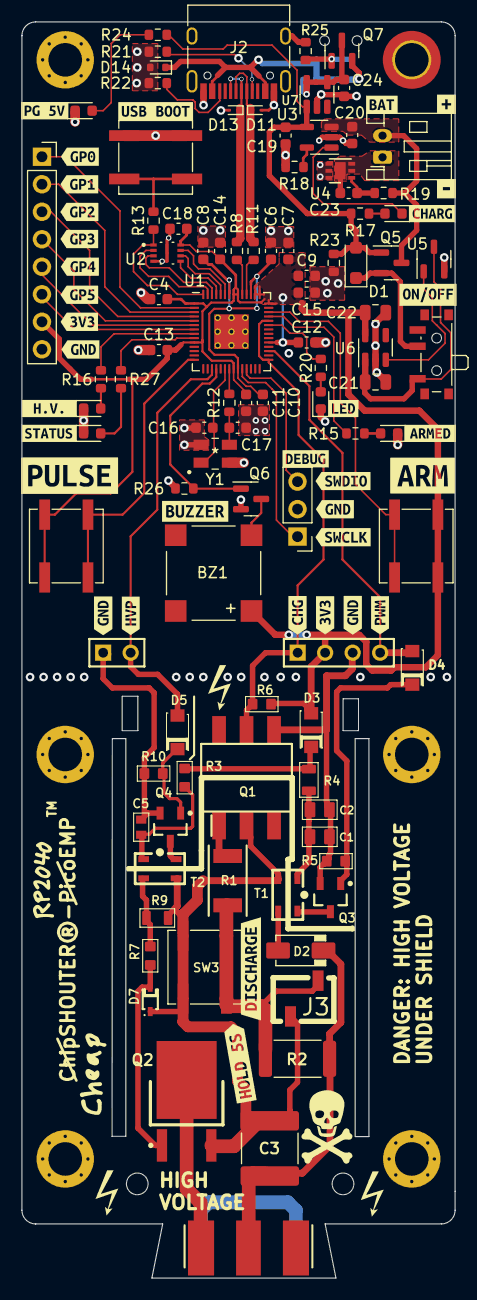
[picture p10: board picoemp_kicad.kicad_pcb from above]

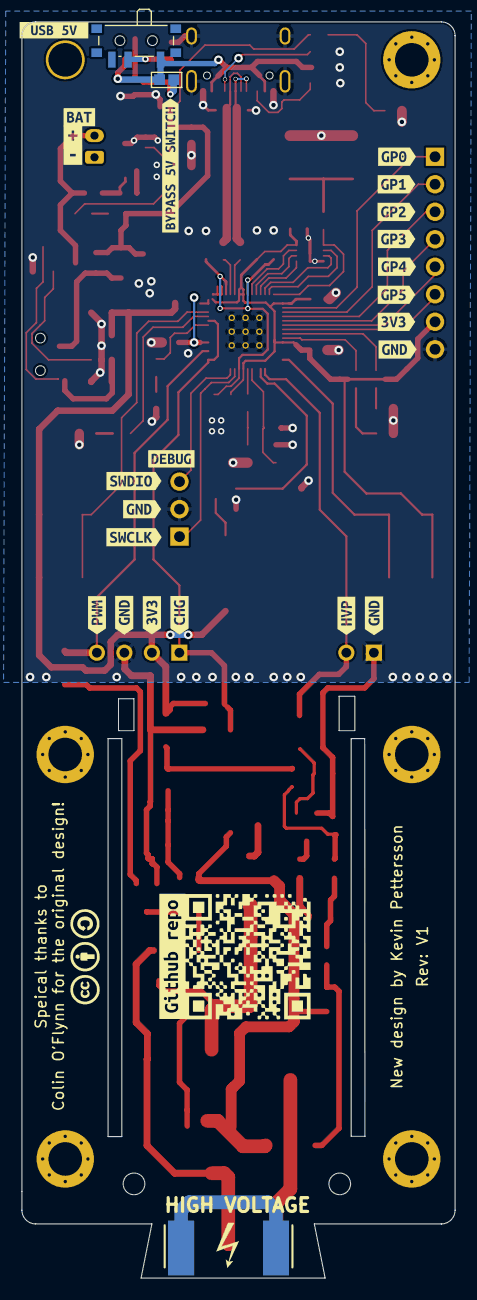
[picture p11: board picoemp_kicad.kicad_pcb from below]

Board: 2 copper layers, 40.0 x 116.0 mm, 161 parts (26 on the bottom side), 71 nets.

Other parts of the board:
C24: 10u; C_0603_1608Metric
MH1, MH1#2, MH1#3, MH1#4, MH1#5: M3, Tight Fit; _Users_colin_Dropbox (NewAE Technology Inc)_engineering_alt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
P2: Header 2; HDR1X2
P3: Header 4; HDR1X4
kibuzzard-63F26E53: G***; kibuzzard-63F26E53
kibuzzard-63F61A8A: G***; kibuzzard-63F61A8A
kibuzzard-63F78E1E, kibuzzard-63F78E1E#2: G***; kibuzzard-63F78E1E
kibuzzard-63F629BA: G***; kibuzzard-63F629BA
kibuzzard-63F668C9: G***; kibuzzard-63F668C9
kibuzzard-63F668D5: G***; kibuzzard-63F668D5
kibuzzard-63F668E9: G***; kibuzzard-63F668E9
kibuzzard-63F668EF: G***; kibuzzard-63F668EF
kibuzzard-63F668F6: G***; kibuzzard-63F668F6
kibuzzard-63F668FC: G***; kibuzzard-63F668FC
kibuzzard-63F2726C: G***; kibuzzard-63F2726C
kibuzzard-63F6135F, kibuzzard-63F6135F#2: G***; kibuzzard-63F6135F
kibuzzard-63F6689E: G***; kibuzzard-63F6689E
kibuzzard-63F65118: G***; kibuzzard-63F65118
kibuzzard-63F66756: G***; kibuzzard-63F66756
kibuzzard-63F66885: G***; kibuzzard-63F66885
kibuzzard-63FA0F3A: G***; kibuzzard-63FA0F3A
kibuzzard-63FA1A3D: G***; kibuzzard-63FA1A3D
kibuzzard-63FA16E2, kibuzzard-63FA16E2#2: G***; kibuzzard-63FA16E2
kibuzzard-63FA1685: G***; kibuzzard-63FA1685
kibuzzard-63FB3D52: G***; kibuzzard-63FB3D52
kibuzzard-63FB28A8: G***; kibuzzard-63FB28A8
kibuzzard-63FB28B5: G***; kibuzzard-63FB28B5
kibuzzard-63FB254D: G***; kibuzzard-63FB254D
kibuzzard-63FB255A: G***; kibuzzard-63FB255A
kibuzzard-63FB256F: G***; kibuzzard-63FB256F
kibuzzard-63FB271A, kibuzzard-63FB271A#2: G***; kibuzzard-63FB271A
kibuzzard-63FB287B: G***; kibuzzard-63FB287B
kibuzzard-63FB2541: G***; kibuzzard-63FB2541
kibuzzard-63FB2554: G***; kibuzzard-63FB2554
kibuzzard-63FB2562: G***; kibuzzard-63FB2562
kibuzzard-63FB2568: G***; kibuzzard-63FB2568
kibuzzard-63FB2575: G***; kibuzzard-63FB2575
kibuzzard-63FB2610, kibuzzard-63FB2610#2: G***; kibuzzard-63FB2610
kibuzzard-63FB2711, kibuzzard-63FB2711#2, kibuzzard-63FB2711#3, kibuzzard-63FB2711#4: G***; kibuzzard-63FB2711
kibuzzard-63FB2724, kibuzzard-63FB2724#2: G***; kibuzzard-63FB2724
kibuzzard-63FB2766, kibuzzard-63FB2766#2: G***; kibuzzard-63FB2766
kibuzzard-63FB2882: G***; kibuzzard-63FB2882
kibuzzard-63FB2887: G***; kibuzzard-63FB2887
kibuzzard-63FB2899: G***; kibuzzard-63FB2899
kibuzzard-63FF3009: G***; kibuzzard-63FF3009
kibuzzard-640062E5: G***; kibuzzard-640062E5
kibuzzard-640065CA: G***; kibuzzard-640065CA
kibuzzard-640384C5: G***; kibuzzard-640384C5
kibuzzard-640385A5: G***; kibuzzard-640385A5
kibuzzard-640461F9: G***; kibuzzard-640461F9
kibuzzard-6403912E: G***; kibuzzard-6403912E
kibuzzard-64031476: G***; kibuzzard-64031476

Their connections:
CHARGED: P3.1; also elsewhere on the board
GND: C24.2, P2.1, P3.3; also elsewhere on the board
HVPULSE: P2.2; also elsewhere on the board
HVPWM: P3.4; also elsewhere on the board

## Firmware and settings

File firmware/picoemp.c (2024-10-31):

#include "picoemp.h"

#include "hardware/gpio.h"
#include "hardware/pwm.h"
#include "hardware/clocks.h"
#include "pico/stdlib.h"

#include <stdio.h>

const uint32_t PIN_IN_TRIGGER = 0; // also GP0 on the board
const uint32_t PIN_LED_HV = 6;
const uint32_t PIN_LED_STATUS = 7;
const uint32_t PIN_BTN_PULSE = 11;
const uint32_t PIN_OUT_HVPULSE = 14;
const uint32_t PIN_IN_CHARGED = 18;
const uint32_t PIN_OUT_HVPWM = 20;
const uint32_t PIN_LED_CHARGE_ON = 27;
const uint32_t PIN_BTN_ARM = 28;
const uint32_t PIN_BUZZER = 15;

static bool pwm_enabled = false;

// Code from https://www.i-programmer.info/programming/hardware/14849-the-pico-in-c-basic-pwm.html?start=2
uint32_t pwm_set_freq_duty(uint slice_num,
       uint chan, uint32_t f, float d)
{
    uint32_t clock = clock_get_hz(clk_sys);
    uint32_t divider16 = clock / f / 4096 + (clock % (f * 4096) != 0);
    
    if (divider16 / 16 == 0)
        divider16 = 16;
    
    uint32_t wrap = clock * 16 / divider16 / f - 1;
    
    pwm_set_clkdiv_int_frac(slice_num, divider16/16, divider16 & 0xF);
    pwm_set_wrap(slice_num, wrap);
    pwm_set_chan_level(slice_num, chan, (int)((float)wrap * d));
    
    return wrap;
}

void picoemp_enable_pwm(float duty_frac) {
    if(pwm_enabled) {
        return;
    }

    // Get PWM slice
    uint32_t slice = pwm_gpio_to_slice_num(PIN_OUT_HVPWM);
    gpio_set_function(PIN_OUT_HVPWM, GPIO_FUNC_PWM);
    
    // Set up clock divider
    float target_frequency = 25;
    float divider = clock_get_hz(clk_sys) / target_frequency;
    pwm_config config = pwm_get_default_config();
    pwm_config_set_clkdiv(&config, divider);
    pwm_config_set_wrap(&config, UINT16_MAX);

    // Init PWM, but don't start it yet
    pwm_init(slice, &config, false);
    // pwm_set_chan_level(slice, PWM_CHAN_A, 800); // pretty sure this line is pointless
    pwm_set_freq_duty(slice, PWM_CHAN_A, 2500, duty_frac);
    pwm_set_enabled(slice, true);
    pwm_enabled = true;
}

void init_buzzer() {
    // Get PWM slice
    uint32_t slice = pwm_gpio_to_slice_num(PIN_BUZZER);
    gpio_set_function(PIN_BUZZER, GPIO_FUNC_PWM);
    
    // Set up clock divider
    float target_frequency = 25;
    float divider = clock_get_hz(clk_sys) / target_frequency;
    pwm_config config = pwm_get_default_config();
    pwm_config_set_clkdiv(&config, divider);
    pwm_config_set_wrap(&config, UINT16_MAX);

    // Init PWM, but don't start it yet
    pwm_init(slice, &config, false);
    pwm_set_freq_duty(slice, PWM_CHAN_B, 80, 0.2);
    pwm_set_enabled(slice, false);
}

void buzzer_on() {
    uint32_t slice = pwm_gpio_to_slice_num(PIN_BUZZER);
    pwm_set_enabled(slice, true);
}

void buzzer_off() {
    uint32_t slice = pwm_gpio_to_slice_num(PIN_BUZZER);
    pwm_set_enabled(slice, false);
}

void picoemp_disable_pwm() {
    pwm_enabled = false;
    gpio_init(PIN_OUT_HVPWM);
    gpio_set_dir(PIN_OUT_HVPWM, GPIO_OUT);
    gpio_put(PIN_OUT_HVPWM, false);
}

void picoemp_pulse(uint32_t pulse_time) {
    gpio_put(PIN_OUT_HVPULSE, true);
    buzzer_on();
    sleep_us(pulse_time);
    gpio_put(PIN_OUT_HVPULSE, false);
    sleep_ms(250);
    buzzer_off();
}

void picoemp_configure_pulse_output() {
    // Configure pulse output
    gpio_init(PIN_OUT_HVPULSE);
    gpio_set_dir(PIN_OUT_HVPULSE, GPIO_OUT);
    // No pullups & pulldowns
    gpio_set_pulls(PIN_OUT_HVPULSE, false, false);
    // Adjust slew-rate & drive strength. 
    gpio_set_drive_strength(PIN_OUT_HVPULSE, GPIO_DRIVE_STRENGTH_12MA);
    gpio_set_slew_rate(PIN_OUT_HVPULSE, GPIO_SLEW_RATE_FAST);
    gpio_put(PIN_OUT_HVPULSE, false);
}

void picoemp_configure_pulse_external() {
    // Configure pulse input
    gpio_init(PIN_OUT_HVPULSE);
    gpio_set_dir(PIN_OUT_HVPULSE, GPIO_IN);
    // No pullups & pulldowns
    gpio_set_pulls(PIN_OUT_HVPULSE, false, false);
}

void picoemp_init() {
    // Initialize LED GPIOs
    gpio_init(PIN_LED_HV);
    gpio_init(PIN_LED_STATUS);
    gpio_init(PIN_LED_CHARGE_ON);
    gpio_set_dir(PIN_LED_HV, GPIO_OUT);
    gpio_set_dir(PIN_LED_STATUS, GPIO_OUT);
    gpio_set_dir(PIN_LED_CHARGE_ON, GPIO_OUT);
    // Enable status LED
    gpio_put(PIN_LED_STATUS, true);

    // Initialize button GPIOs
    gpio_init(PIN_BTN_ARM);
    gpio_init(PIN_BTN_PULSE);
    gpio_set_dir(PIN_BTN_ARM, GPIO_IN);
    gpio_set_dir(PIN_BTN_PULSE, GPIO_IN);
    // ARM is active high, PULSE is active low
    // Enable ARM pulldown
    gpio_set_pulls(PIN_BTN_ARM, false, true);
    // Enable PULSE pulldown
    gpio_set_pulls(PIN_BTN_PULSE, false, true);

    // Charge-detection coming from HV side
    gpio_init(PIN_IN_CHARGED);
    gpio_set_dir(PIN_IN_CHARGED, GPIO_IN);
    gpio_set_pulls(PIN_IN_CHARGED, false, false);
    // Charge is active-low, so we invert it to make the code seem
    // more logical
    gpio_set_inover(PIN_IN_CHARGED, GPIO_OVERRIDE_INVERT);

    // Configure pulse output
    picoemp_configure_pulse_output();

    // Configure PWM pin
    picoemp_disable_pwm();

    // Configure buzzer
    init_buzzer();
}

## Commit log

2023-02-20 Inital commit
    [high_voltage.kicad_sch, mcu.kicad_sch, picoemp_kicad.kicad_pcb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]
2023-02-21 Swapped charging IC for reduced footprint
    [picoemp_kicad.kicad_pcb, power.kicad_sch]
2023-02-26 finalized schematic + layout
    [bom.csv, designators.csv, high_voltage.kicad_sch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]
2023-03-01 Small tweaks
    [mcu.kicad_sch, picoemp_kicad.kicad_pcb, power.kicad_sch]
2023-03-04 finishing touches
    [bom.csv, designators.csv, high_voltage.kicad_sch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]
2023-03-05 Minor adjustment to silkscreen
    [designators.csv, picoemp_kicad.kicad_pcb]
2023-03-05 Minor adjustment silkscreen

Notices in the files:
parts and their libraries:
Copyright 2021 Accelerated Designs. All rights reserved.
